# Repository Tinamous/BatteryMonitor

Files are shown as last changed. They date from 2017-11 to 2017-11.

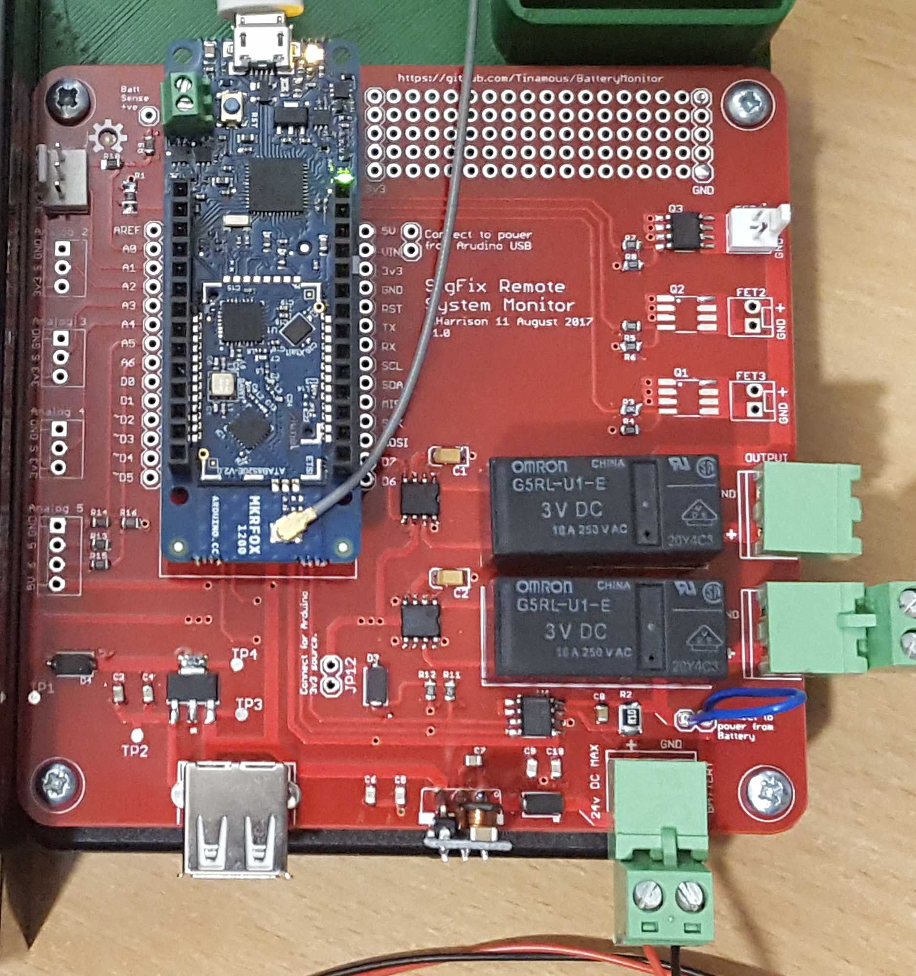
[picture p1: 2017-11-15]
Arduino/Images/Assembled2.jpg

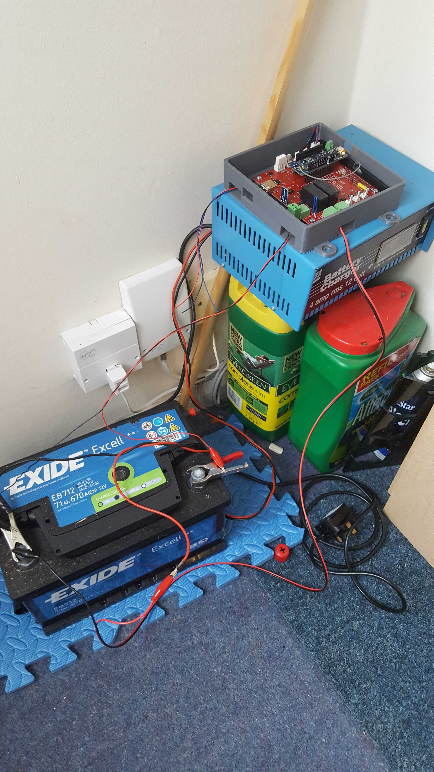
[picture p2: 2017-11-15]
Arduino/Images/TestSetup.jpg

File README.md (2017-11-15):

Internet Of Things Remote System Monitor
========================================

For remote locations a battery powered devices may be the only realistic way of powering equipment, these may be left to work for months or years until one day the battery dies or goes flat unexpectedly or something else happens.

This project uses the Sigfox Arduino MKR FOX 1200 to provide low power wireless internet connectivity and a INA219 to monitor the battery. This allows monitor and early notification of problems.

Additionally 2x latching relays, 3x N-Channel fets and some digital/analog inputs provide means to monitor other parts of a system as well (e.g. monitor switches, water levels, control pumps, lights etc.).

The system is composed of:

* Arduino MKR FOX 1200 Sigfox based Arduino.
* INA219 power monitor (0R1 resistor - limited to 2A due to package size).
* 2x Latching relays for output and charger input.
* 3x N-Channel FET outputs.
* 6x Analog input connectors (4x 3 pin with GND, 3v3 and signal, 1x 4 pin with GND 5V and 2x signal divided to allow 5V analog).
* On-board 5V buck regulator from the battery.
* On-board 3v3 regulator for relay and analog connectors.
* Mini prototyping area.
* Always on USB A power output.

Primary Use Case - Garage
=========================

* 12V Lead Acid Battery (i.e. car battery) connected to the battery input
* Powered system connected to the output (humidity controlled boxes).
* Solar charger connected to charger connector.
* LED lighting connected to FET1, 2 and 3.

Alternative Usages:
* The battery connector can be used as an output with inputs from 2 batteries or a power supply and battery allowing a backup power source to be switched in should the primary fall out of acceptable range. In this case the power measurement is purely for output and does not include power used through the FET outputs, analog inputs or the system itself.

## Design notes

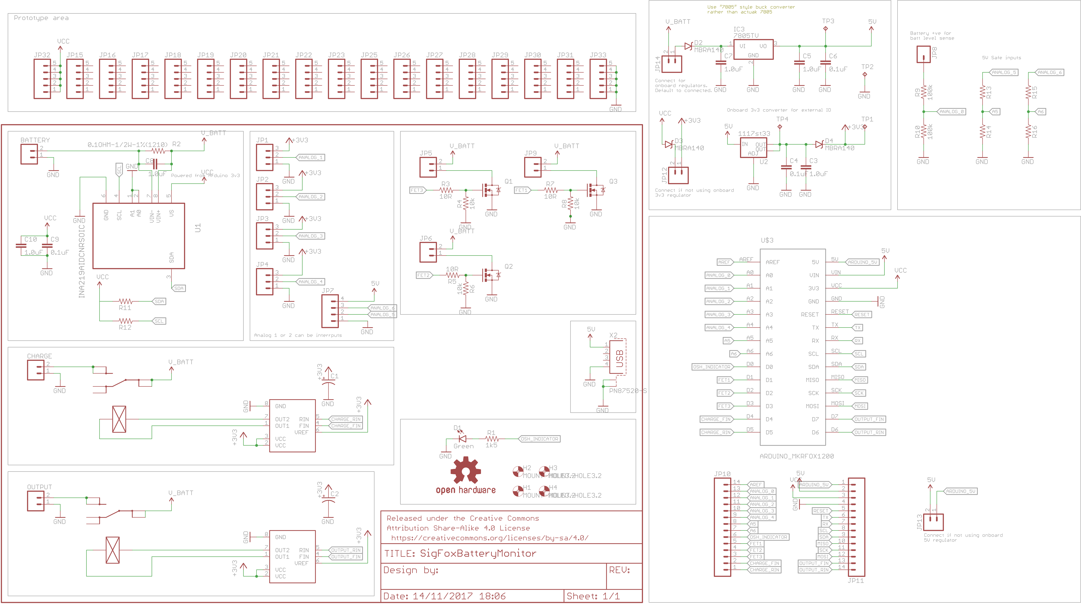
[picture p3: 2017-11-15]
Arduino/Images/Schematic.png

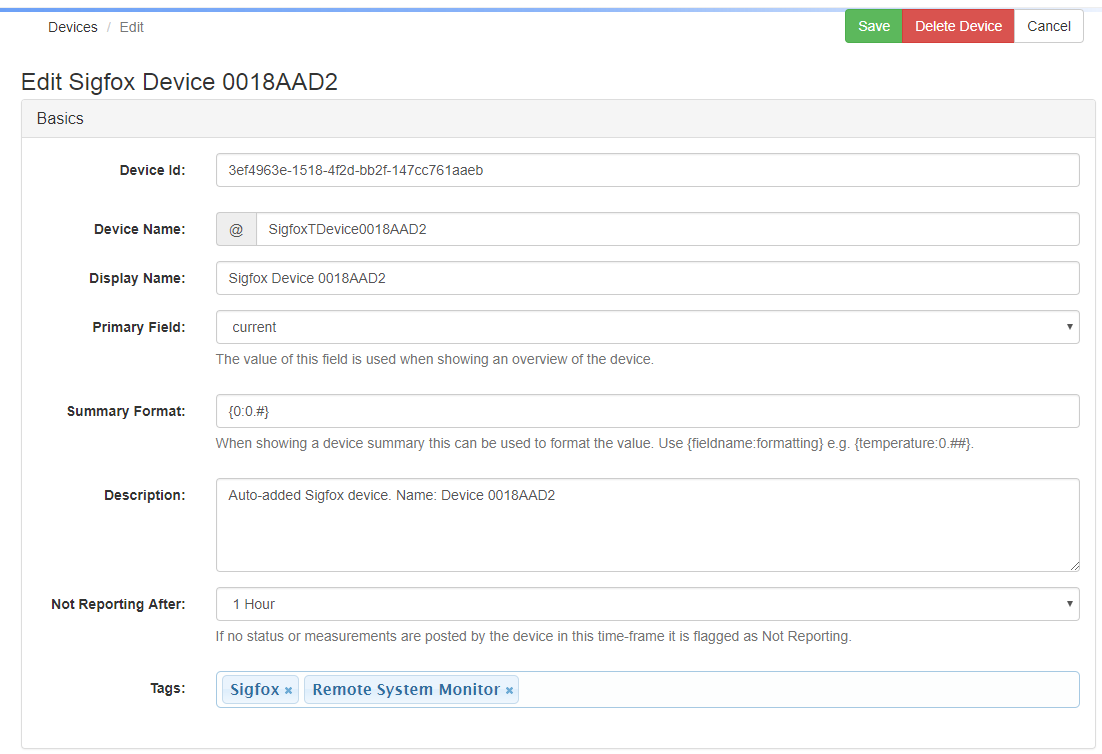
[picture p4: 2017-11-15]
Arduino/Images/EditDevice.png

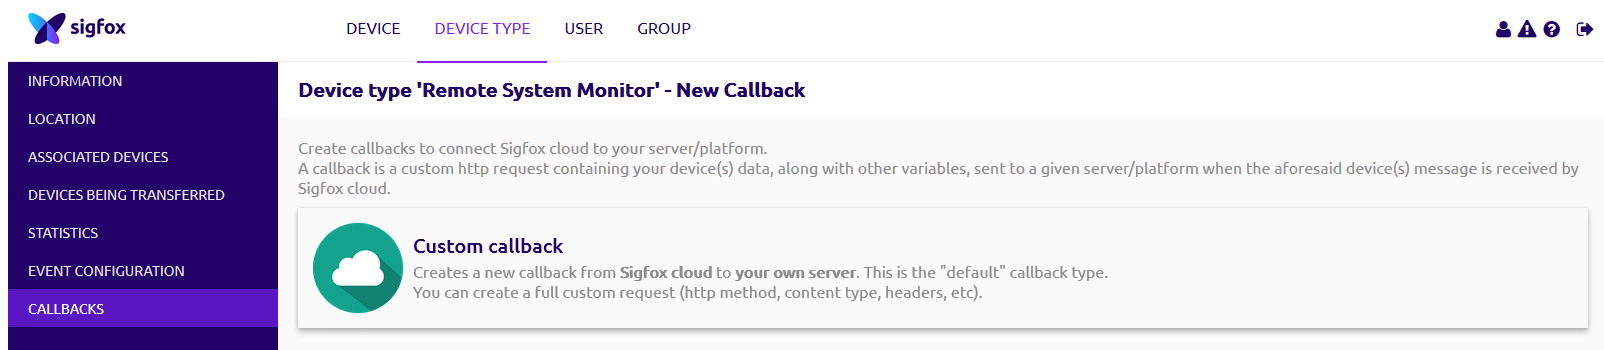
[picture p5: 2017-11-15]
Arduino/Images/CustomCallback.png

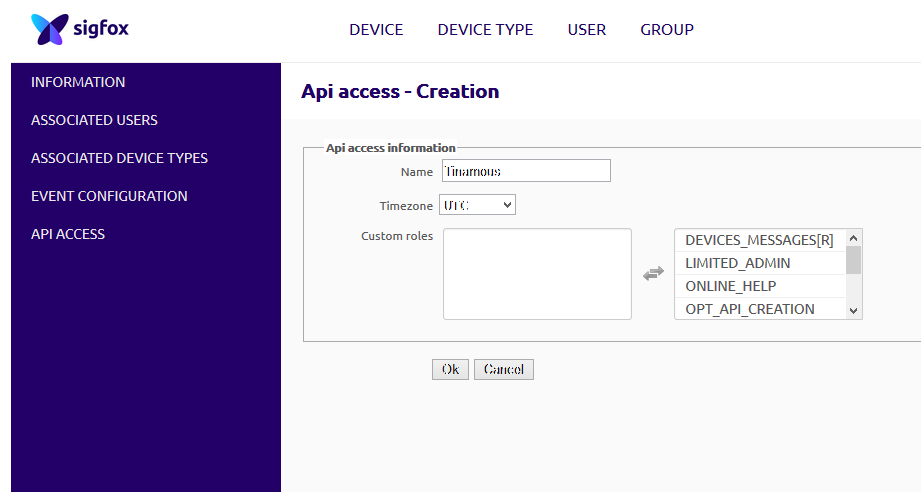
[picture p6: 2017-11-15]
Arduino/Images/ApiSettings.png

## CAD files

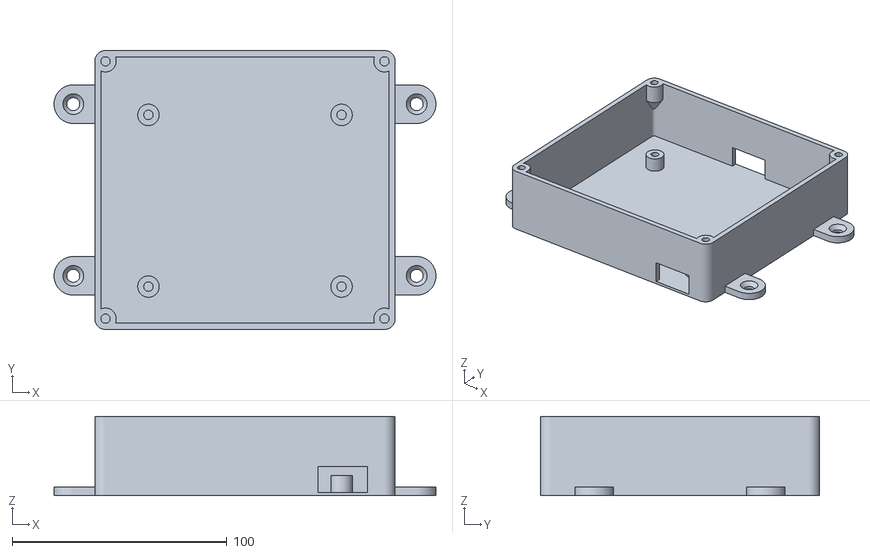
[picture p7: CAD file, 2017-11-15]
Arduino/Case/GarageLightsControllerBox.stl
178.0 x 130.0 x 37.0

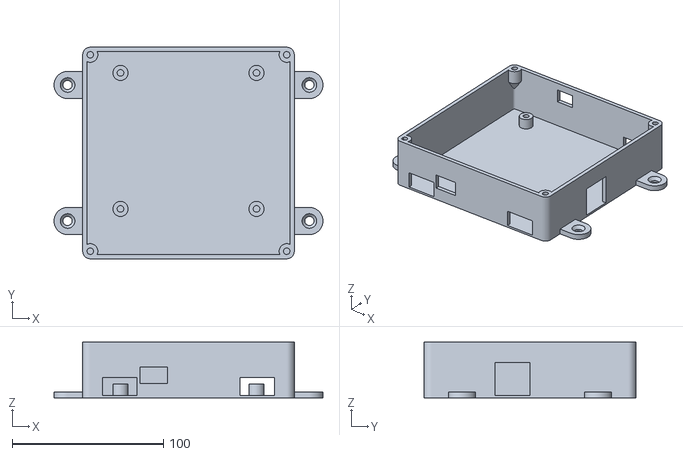
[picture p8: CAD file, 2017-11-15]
Arduino/Case/BatteryMonitorCase.stl
178.0 x 140.0 x 37.0

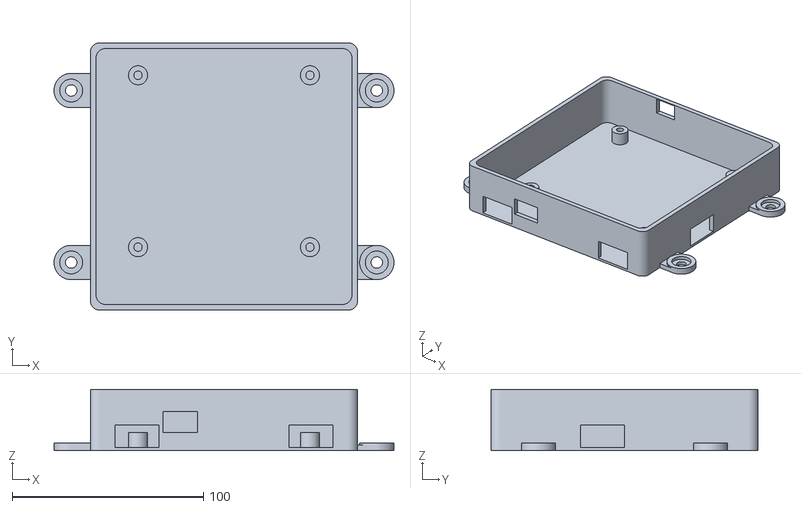
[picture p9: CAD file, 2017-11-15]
Arduino/Case/BatteryMonitorCase-LowerTrunking.stl
178.0 x 140.0 x 32.0

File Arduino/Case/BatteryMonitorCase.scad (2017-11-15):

$fn=80;

// Width (Note pcb does not centre align).
// 120mm realisting minimum size
// with trunking
// Width of 140mm allows the aerial to be stuck to the top edge
width = 140;

// Overall length /mm (without aerial 117mm, With aerial 125mm)
length = 140;

//enclosureHeight = 32; // Max for USB being in top part.
enclosureHeight = 37; // Max for USB being in top part.

// 100x100 for general PCB
pcbWidth = 100; // x direction
pcbLength = 100; // y direction
// Offset from edge for the PCB mounting hole
pcbMountOffset = 5;


pcbXOffset = (width - pcbWidth)/2 ;
//pcbYOffset = (length - pcbLength)/2 + 10;
// Keep the PCB 10mm from the top edge
// allows the aerial to be stuck down.
// make gap 21mm for Arduiono MRK 1000 (WiFi)
pcbYOffset = (length - pcbLength - 12); 

// Kitchen Lights
// Center.
//pcbYOffset = (length - pcbLength - 25);

echo ("pcbXOffset",pcbXOffset);
echo ("pcbYOffset",pcbYOffset);

// 20mm border around the PCB for connectors.

// Thickness of the base material.
baseHeight = 1.5;

// How height off the base the PCB wil lbe.
height = 8;

//wallThickness = 1.5;
wallThickness = 3;

// Diameter of the screw hole for the PCB mounts. 4.4mm works well for M3 heatfits.
pcbMountScrewHoleDiameter = 4.4;

// caseOptions

addPowerSideHoles = true;
addFetHoles = false; 
addSensorSideHoles = false;
addArduinoUsbHole = true;

// Top 
addTopMiddleRoundConduitHole = false;
addTopRightTrunkingInlet = true;
addTopCenterTrunkingInlet = false;

// Bottom
addMiddleRoundConduitHole = false;
addTwinConduitHoles = false;
addPowerLowerTrunkingInlet = true;
addSecondLowerTrunkingInlet = true;
addUsbOutletHole = true;

addMountingTabs = true;

conduitHoleDiameter = 22;

mountingTabYOffset = 25;
countersunkMountingScrews = true;

// Screw or threaded insert
lidScrewDiameter = pcbMountScrewHoleDiameter; //4.4
includeLidScrewMounts = true;
            
// Make it a nice distance appart for the holes.
// that doesn't change if the case is made larger
// allowing it to be swapped out.
twinHolesDistanceApart = 45;  // Gives round hole by USB...
//twinHolesDistanceApart = 90; // On the edges - good for USB access
twinHolesXOffset = (width - twinHolesDistanceApart) / 2;

module roundedCube(width, height, depth, cornerDiameter) {
//cornerDiameter = 5;
cornerRadius = cornerDiameter/2;

    translate([cornerDiameter/2,0,0]) {
        cube([width-cornerDiameter, height, depth]);
    }
    
    translate([0,cornerDiameter/2,0]) {
        cube([width, height-cornerDiameter, depth]);
    }
    
    translate([cornerRadius,cornerRadius,0]) {
        cylinder(d=cornerDiameter, h=depth);
    }
    
    translate([width-cornerRadius,cornerRadius,0]) {
        cylinder(d=cornerDiameter, h=depth);
    }
    
    translate([cornerRadius,height-cornerRadius,0]) {
        cylinder(d=cornerDiameter, h=depth);
    }
    
    translate([width-cornerRadius,height-cornerRadius,0]) {
        cylinder(d=cornerDiameter, h=depth);
    }
}

module screw(x,y, height) {
    translate([x,y, 0]) {
        cylinder(d=6.5, h=2);
    }
    
    translate([x,y, -4]) {
        cylinder(d=3, h=6);
    }
}

module genericPcb() {
    
//pcbWidth = 100;
//pcbLength = 100;
// Offset from edge for the PCB mounting hole
//pcbMountOffset = 5;
    
    roundedCube(pcbWidth,pcbLength , 1.6, 8);
    screw(pcbMountOffset, pcbMountOffset, height, baseHeight);
    screw(pcbMountOffset,pcbLength - pcbMountOffset, height, baseHeight);
    screw(pcbWidth - pcbMountOffset, pcbMountOffset, height, baseHeight);
    screw(pcbWidth - pcbMountOffset,pcbLength - pcbMountOffset, height, baseHeight);
}

// Arduino System Monitor PCB.
module arduinoSystemMonitorPcb() {
    roundedCube(100,100, 1.6, 8);
    screw(5,5, height, baseHeight);
    screw(5,95, height, baseHeight);
    screw(95,5, height, baseHeight);
    screw(95,95, height, baseHeight);
    
    // Battery in
    translate([74, -14, 1.6]) {
        cube([12, 22, 14]);
    }
    
    // Charger out
    translate([90, 19, 1.6]) {
        cube([22, 12, 14]);
    }
    
    // Power out
    translate([90, 35, 1.6]) {
        cube([22, 12, 14]);
    }
    
    // FETs
    translate([90, 75, 1.6]) {
        cube([8, 5, 20]);
    }
    
    translate([90, 59+5, 1.6]) {
        cube([8, 5, 20]);
    }
    
    translate([90, 47+5, 1.6]) {
        cube([8, 5, 20]);
    }
    
    // USB socket
    translate([20.5, -25, 1.6]) {
        cube([13.5, 35, 8]);
    }
    
    // USB Plug into the socket
    translate([19.5, -50, 1.6]) {
        cube([15.5, 50, 8]);
    }
    
    // Analog 1..5
    translate([2, 75+5, 1.6]) {
        cube([8, 7, 20]);
    }
    
    translate([2, 63.5+5, 1.6]) {
        cube([8, 7, 20]);
    }
    
    translate([2, 51.5+5, 1.6]) {
        cube([8, 7, 20]);
    }
    
    translate([2, 39.5+5, 1.6]) {
        cube([8, 7, 20]);
    }
    
    translate([2, 24+5, 1.6]) {
        cube([8, 12, 20]);
    }
}

// Actually this needs to be a Sigfor module...
module arduino() {
    // Z position already at PCB top.
    cube([25,68,14.5]);
    // Headers and Battery terminal
    translate([0,10,0]) {
        cube([5,50,23]); // Includes battery connector
        translate([20,0,0]) {
            cube([5,36,23]);
        }
    }
      
    // USB
    translate([8, 68-5.5, 14.5]) {
        cube([8,5.5,3]);
    }
    
    // USB Plug
    translate([8 - (3/2), 68, 14.5 - 3]) {
        cube([11,22,8]);
    }
    
    // Aerial connector
    translate([16, 5, 24]) {
        cube([8,4,2.5]);
    }
}

module pcbMount(x,y, height, baseHeight) {
    translate([x,y, baseHeight-0.1]) {
        difference() {
            cylinder(d=10, h=height);
            cylinder(d=pcbMountScrewHoleDiameter, h=height);
        }
    }
}

module pcbMountPin(x,y, height, baseHeight) {
    translate([x,y, baseHeight-0.1]) {
        union() {
            cylinder(d=10, h=height);
            cylinder(d=pcbMountPinDiameter, h=height + 3);
        }
    }
}

module addPcbMounts() {
    
    //pcbWidth = 100;
    //pcbLength = 100;
    // Use pins on the end two to make it easier to 
    pcbMount(pcbMountOffset,pcbMountOffset, height, baseHeight);
    #pcbMount(pcbWidth - pcbMountOffset,pcbMountOffset, height, baseHeight);
    
    pcbMount(pcbMountOffset,pcbLength - pcbMountOffset, height, baseHeight);
    pcbMount(pcbWidth - pcbMountOffset,pcbLength - pcbMountOffset, height, baseHeight);
}

module base() {       

// Offset from Pcb X for the Power In port.    
//powerInPcbOffset = 69; // Align with PCB
powerInPcbOffset = 84; // Gives trunking holes on edge (works better for USB.)
trunkingPortWidth = 23;
// Make a second trunking inlet on the lower
// part and make it's offset from the left
// symetrical with the power inlet.
secondTrunkingXOffset = width - (pcbXOffset + powerInPcbOffset + trunkingPortWidth);
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

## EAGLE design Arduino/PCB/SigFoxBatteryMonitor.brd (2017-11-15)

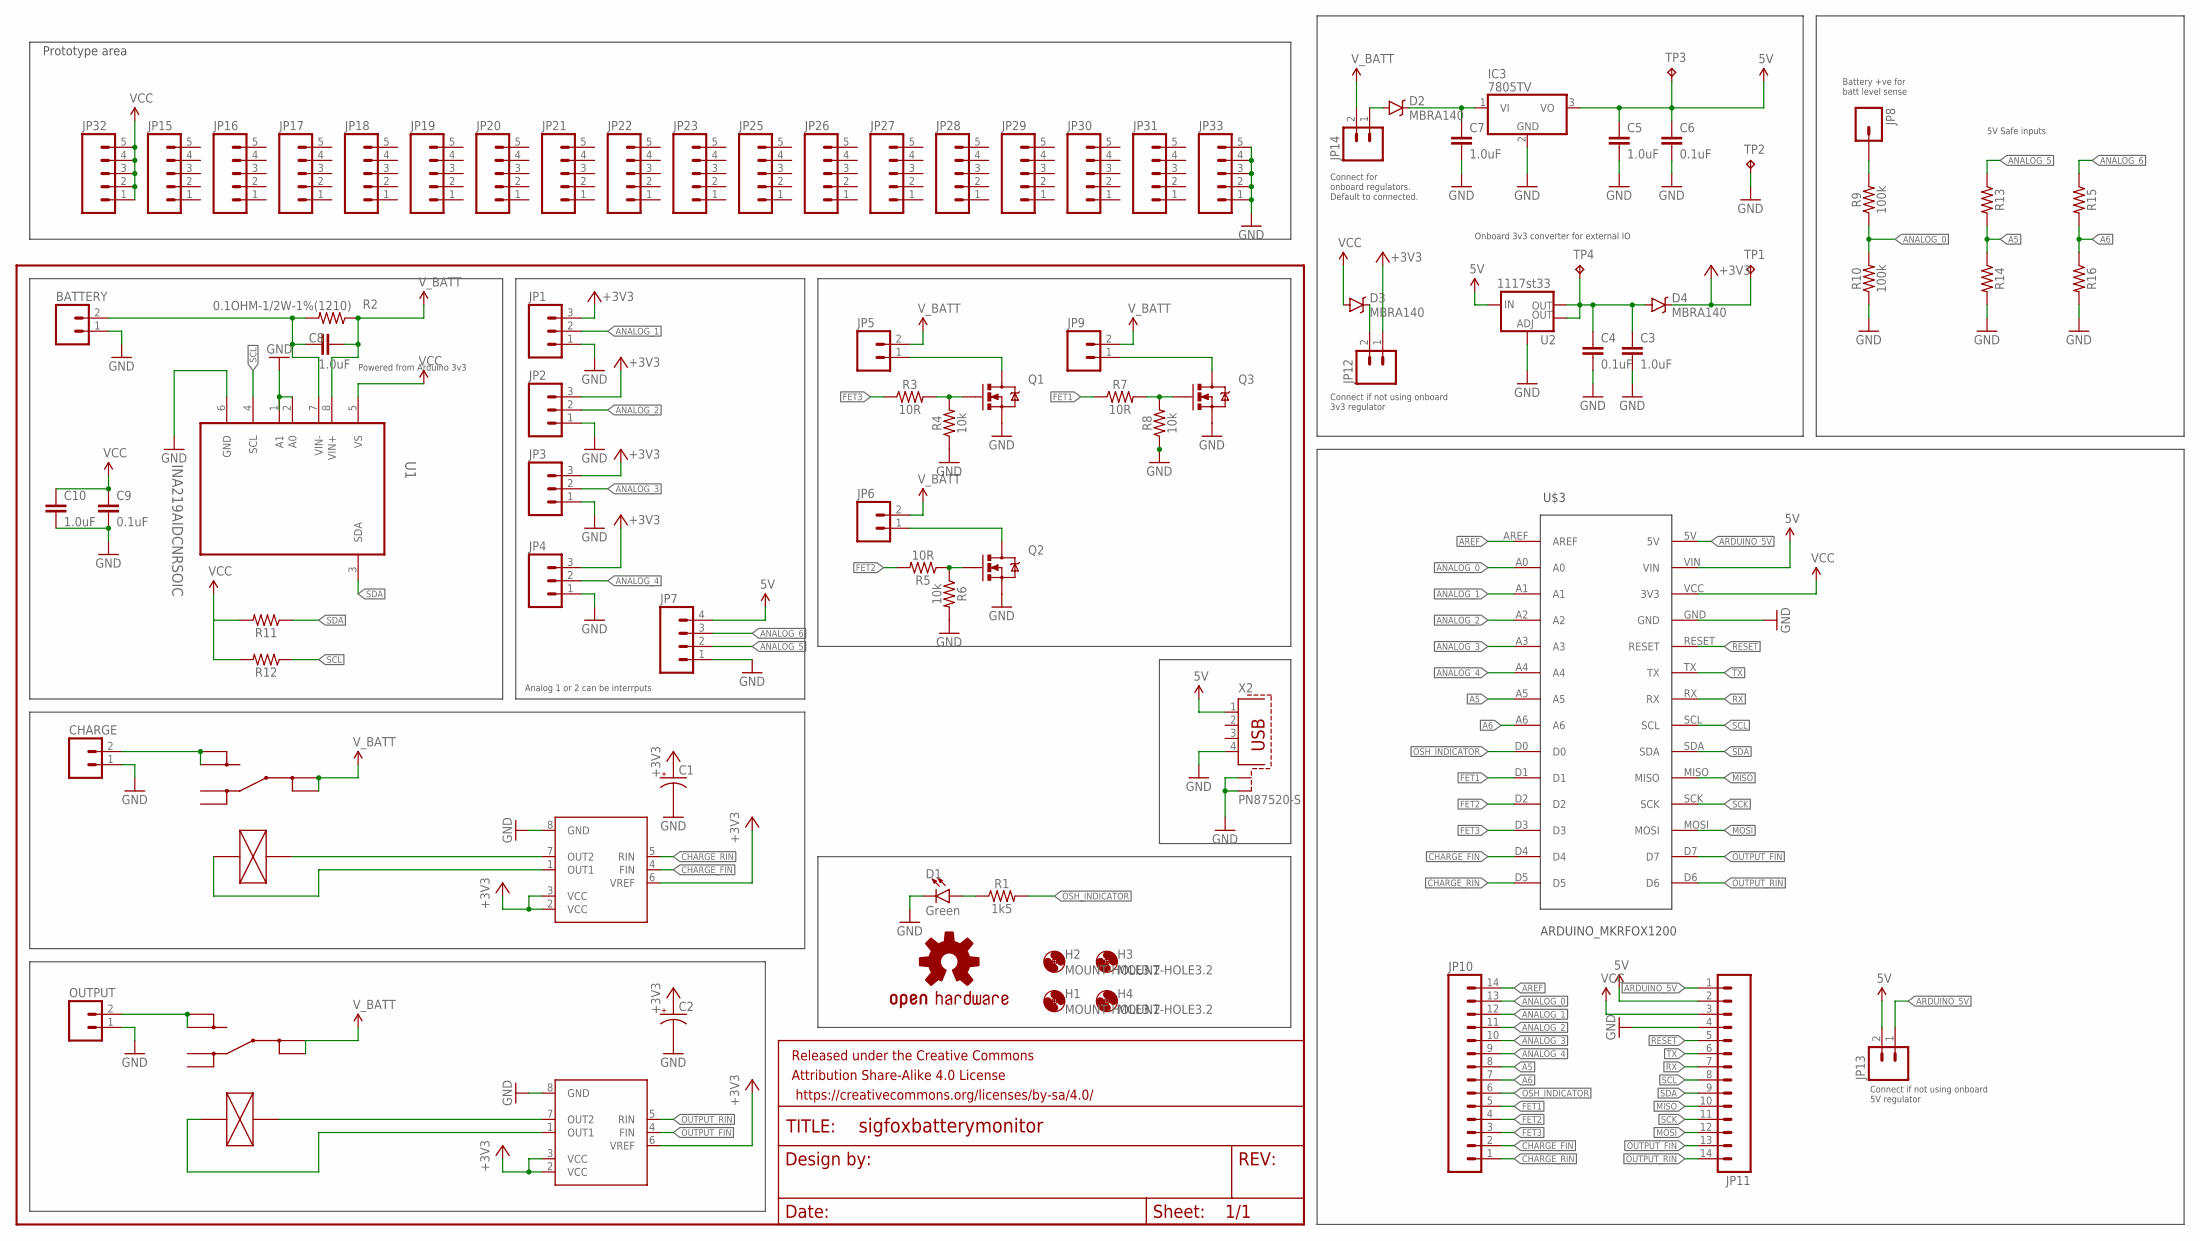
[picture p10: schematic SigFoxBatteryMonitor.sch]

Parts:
BATTERY: M025MM; SCREWTERMINAL-5MM-2; FARNELL 2493689
C1, C2: CAP_POL1206; EIA3216; FARNELL 1457413
C3, C5, C7, C8, C10: 1.0uF; 0805
C4, C6, C9: 0.1uF; 0805
CHARGE: M025MM; SCREWTERMINAL-5MM-2; FARNELL 2493689
D1: Green; LED-1206-BOTTOM
D2, D3, D4: MBRA140; SMA-DIODE
FRAME1: FRAME-LETTER; CREATIVE_COMMONS
H1, H2, H3, H4: MOUNT-HOLE3.2; 3,2
IC1, IC2: BD6211F; SOP8; FARNELL 1716256
IC3: 7805TV; TO220V
JP1, JP2, JP3, JP4: M03POLAR; MOLEX-1X3
JP5, JP6, JP9: M02POLAR; MOLEX-1X2
JP7: M04POLAR; MOLEX-1X4
JP8: M01PTH; 1X01
JP10, JP11: M14; 1X14
JP12, JP13, JP14: M02PTH; 1X02
JP15, JP16, JP17, JP18, JP19, JP20, JP21, JP22, JP23, JP25, JP26, JP27, JP28, JP29, JP30, JP31: M05NO_SILK; 1X05_NO_SILK
JP32, JP33: M05PTH; 1X05
LOGO1: OSHW-LOGOM; OSHW-LOGO-M
OUTPUT: M025MM; SCREWTERMINAL-5MM-2; FARNELL 2493689
Q1, Q2, Q3: IRF7413Z; SO08; FARNELL 2468020
R1: 1k5; 1206
R2: 0.1OHM-1/2W-1%(1210); 1210
R3, R5, R7: 10R; 0805
R4, R6, R8: 10k; 0805
R9, R10: 100k; 0805
R11, R12, R13, R14, R15, R16: 0805
TP1: 3v3; TP15R
TP2: GND; TP15R
TP3, TP4: 5v; TP15R
U1: INA219AIDCNRSOIC; SO08
U2: 1117st33; SOT223; FARNELL 1652366
U$1, U$2: RELAY_G5RL-1E; G5RL-1E; FARNELL 2432863
U$3: ARDUINO_MKRFOX1200
X2: PN87520-S

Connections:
5V: C5.1, C6.1, IC3.3 (VO), JP7.4, JP11.2, JP13.2, TP3.TP, U2.3 (IN), U$3.VIN, X2.1
+3V3: C1.A (+), C2.A (+), D4.C, IC1.2 (VCC), IC1.3 (VCC), IC1.6 (VREF), IC2.2 (VCC), IC2.3 (VCC), IC2.6 (VREF), JP1.3, JP2.3, JP3.3, JP4.3, JP12.1, TP1.TP
A5: JP10.8, R13.2, R14.1, U$3.A5
A6: JP10.7, R15.2, R16.1, U$3.A6
ANALOG_0: JP10.13, R9.1, R10.2, U$3.A0
ANALOG_1: JP1.2, JP10.12, U$3.A1
ANALOG_2: JP2.2, JP10.11, U$3.A2
ANALOG_3: JP3.2, JP10.10, U$3.A3
ANALOG_4: JP4.2, JP10.9, U$3.A4
ANALOG_5: JP7.2, R13.1
ANALOG_6: JP7.3, R15.1
ARDUINO_5V: JP11.1, JP13.1, U$3.5V
AREF: JP10.14, U$3.AREF
CHARGE_FIN: IC1.4 (FIN), JP10.2, U$3.D4
CHARGE_RIN: IC1.5 (RIN), JP10.1, U$3.D5
FET1: JP10.5, R7.1, U$3.D1
FET2: JP10.4, R5.2, U$3.D2
FET3: JP10.3, R3.1, U$3.D3
GND: BATTERY.1, C1.C (-), C2.C (-), C3.2, C4.2, C5.2, C6.2, C7.2, C9.2, C10.2, CHARGE.1, D1.C, IC1.8 (GND), IC2.8 (GND), IC3.2 (GND), JP1.1, JP2.1, JP3.1, JP4.1, JP7.1, JP11.4, JP33.1, JP33.2, JP33.3, JP33.4, JP33.5, OUTPUT.1, Q1.1 (S), Q1.2 (S), Q1.3 (S), Q2.1 (S), Q2.2 (S), Q2.3 (S), Q3.1 (S), Q3.2 (S), Q3.3 (S), R4.1, R6.2, R8.1, R10.1, R14.2, R16.2, TP2.TP, U1.1 (A1), U1.2 (A0), U1.6 (GND), U2.1 (ADJ), U$3.GND, X2.4, X2.S1, X2.S2
MISO: JP11.10, U$3.MISO
MOSI: JP11.12, U$3.MOSI
unnamed: D1.A, R1.1
unnamed: OUTPUT.2, U$1.NO@1 (NO), U$1.NO@2 (NO)
unnamed: CHARGE.2, U$2.NO@1 (NO), U$2.NO@2 (NO)
unnamed: Q1.4 (G), R3.2, R4.2
unnamed: JP5.1, Q1.5 (D), Q1.6 (D), Q1.7 (D), Q1.8 (D)
unnamed: Q3.4 (G), R7.2, R8.2
unnamed: BATTERY.2, C8.1, R2.2, U1.7 (VIN-)
unnamed: IC2.7 (OUT2), U$1.COIL-
unnamed: IC2.1 (OUT1), U$1.COIL+
unnamed: IC1.7 (OUT2), U$2.COIL-
unnamed: IC1.1 (OUT1), U$2.COIL+
unnamed: Q2.4 (G), R5.1, R6.1
unnamed: JP9.1, Q3.5 (D), Q3.6 (D), Q3.7 (D), Q3.8 (D)
unnamed: D3.C, JP12.2
unnamed: JP6.1, Q2.5 (D), Q2.6 (D), Q2.7 (D), Q2.8 (D)
unnamed: JP8.1, R9.2
unnamed: C7.1, D2.C, IC3.1 (VI)
unnamed: D2.A, JP14.1
unnamed: C3.1, C4.1, D4.A, TP4.TP, U2.2 (OUT), U2.4 (OUT)
OSH_INDICATOR: JP10.6, R1.2, U$3.D0
OUTPUT_FIN: IC2.4 (FIN), JP11.13, U$3.D7
OUTPUT_RIN: IC2.5 (RIN), JP11.14, U$3.D6
RESET: JP11.5, U$3.RESET
RX: JP11.7, U$3.RX
SCK: JP11.11, U$3.SCK
SCL: JP11.8, R12.1, U1.4 (SCL), U$3.SCL
SDA: JP11.9, R11.1, U1.3 (SDA), U$3.SDA
TX: JP11.6, U$3.TX
VCC: C9.1, C10.1, D3.A, JP11.3, JP32.1, JP32.2, JP32.3, JP32.4, JP32.5, R11.2, R12.2, U1.5 (VS), U$3.VCC (3V3)
V_BATT: C8.2, JP5.2, JP6.2, JP9.2, JP14.2, R2.1, U1.8 (VIN+), U$1.COM@1 (COM), U$1.COM@2 (COM), U$2.COM@1 (COM), U$2.COM@2 (COM)

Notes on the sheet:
Onboard 3v3 converter for external IO
Powered from Arduino 3v3
Battery +ve for batt level sense
Connect if not using onboard 5V regulator
Connect if not using onboard 3v3 regulator
Connect for onboard regulators. Default to connected.
5V Safe inputs
Analog 1 or 2 can be interrputs
Prototype area

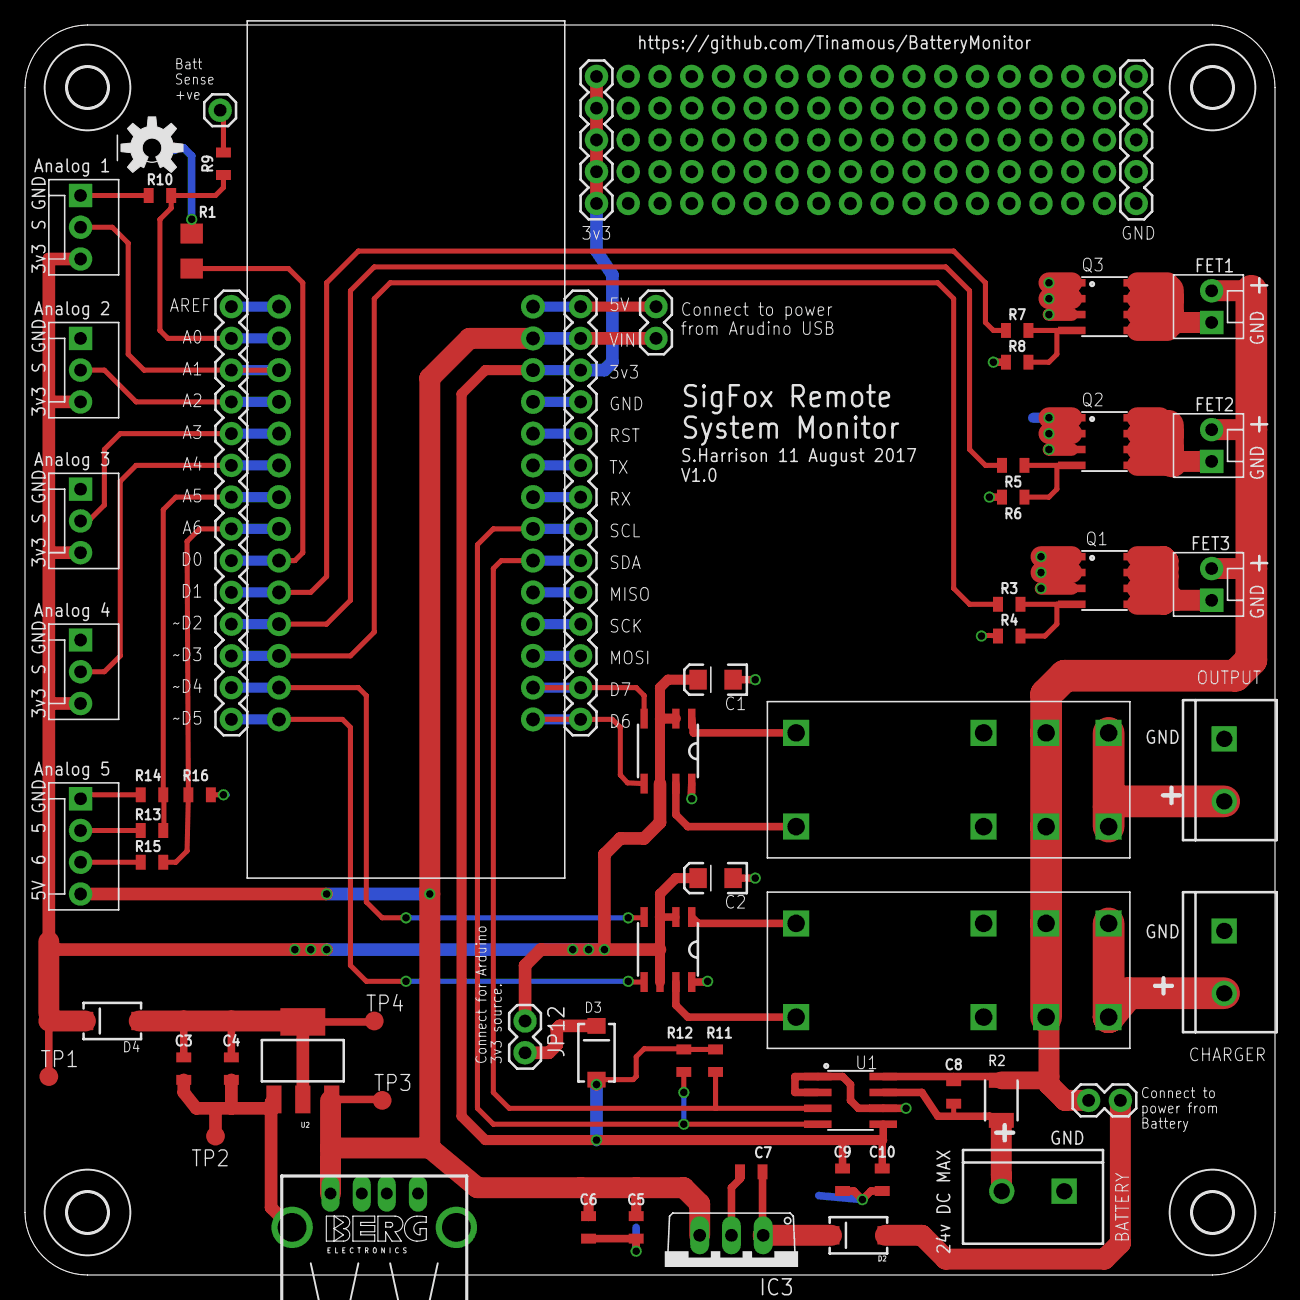
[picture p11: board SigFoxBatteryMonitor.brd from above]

Board: 2 copper layers, 100.0 x 100.0 mm, 87 parts (1 on the bottom side), 51 nets.

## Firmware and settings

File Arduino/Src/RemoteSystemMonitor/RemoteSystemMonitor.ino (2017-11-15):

// Arduino Low Power - Version: Latest 
#include <ArduinoLowPower.h>

// Arduino SigFox for MKRFox1200 - Version: Latest 
#include <SigFox.h>

#include <Wire.h>
#include <Adafruit_INA219.h>

Adafruit_INA219 ina219;

bool fet1State = false;
bool fet2State = false;
bool fet3State = false;
bool outputRelay = false;
bool chargeRelay = false;
bool oshLed = false;

int loopCounter  =0;
bool debug = true;

// First run request downlink data
// from the Sigfox backend.
bool requestDownlinkData = true;

// status::uint:8 version::uint:8 temperature::int:8 current::int:16 voltage::uint:16 humidity::int:16 light::uint:8 light2::uint:8 lastStatus::uint:8
typedef struct __attribute__ ((packed)) sigfox_message {
  uint8_t status;     // status::uint:8 -> Split to 8 bits
  uint8_t version;    // version::uint:8
  int16_t temperature; // temperature::int:16:little-endian
  int16_t current;    // current::int:16:little-endian (e.g. 1159 mA -> 0487 but stored as 8704)
  uint16_t voltage;   // voltage::uint:16:little-endian
  int16_t currentOffCharge;   // currentOffCharge::int:16:little-endian
  uint16_t voltageOffCharge;   // voltageOffCharge::uint:16:little-endian
} SigfoxMessage;

// stub for message which will be sent
SigfoxMessage msg;

void setup() {
  pinMode(0, OUTPUT); // led
  pinMode(1, OUTPUT); // Fet1
  pinMode(2, OUTPUT); // Fet2
  pinMode(3, OUTPUT); // Fet3
  pinMode(4, OUTPUT); // charge relay FIN
  pinMode(5, OUTPUT); // charge relay RIN
  pinMode(6, OUTPUT); // output relay FIN
  pinMode(7, OUTPUT); // output relay RIN
  
  setFetOutput(1, fet1State);
  setFetOutput(2, fet2State);
  setFetOutput(3, fet3State);
  // On to indicate in setup
  setOshLed(true);
  
  // Intialize the relays to off
  // whilst in set-up. Force state so we know
  // the state their in and can then track it.
  setChargeRelay(false, true);
  setOutputRelay(false, true);
  
  //Initialize serial and wait for port to open:
  if (debug) {
    Serial.begin(9600);
  }
     
  // Initialize the INA219.
  // By default to (32V, 2A).  
  ina219.begin();
 
  setupSigfox();  

  if (debug) {
    Serial.println("System Monitor Setup Complete... V0.0.4");
  }
  
  // turn off the OSH Led now set-up is complete.
  setOshLed(false);
}

void setupSigfox() {
  if (!SigFox.begin()) {
    Serial.println("Shield error or not present!");
    return;
  }
  
  // Enable debug led and disable automatic deep sleep
  // Comment this line when shipping your project :)
  if (debug) {
    SigFox.debug();
  }

  // Output the ID and PAC needed to register the 
  // device at the Sigfox backend.
  String version = SigFox.SigVersion();
  String ID = SigFox.ID();
  String PAC = SigFox.PAC();

  // Display module informations
  Serial.println("MKRFox1200 Sigfox first configuration");
  Serial.println("SigFox FW version " + version);
  Serial.println("ID  = " + ID);
  Serial.println("PAC = " + PAC);

  Serial.println("");

  Serial.print("Module temperature: ");
  Serial.println(SigFox.internalTemperature());

  Serial.println("Register your board on https://backend.sigfox.com/activate with provided ID and PAC");

  delay(100);

  // Send the module to the deepest sleep
  SigFox.end();
}

void loop(void) 
{ 
  float shuntvoltage = 0;
  float busvoltage = 0;
  float current_mA = 0;
  float loadvoltage = 0;
  
  // V and I when not charging
  // to give an idea of the state of the battery
  float current_off_charge_mA = 0;
  float busvoltage_off_charge = 0;
 
  // Ensure output relay and charge relay are on by default
  // now that we're monitoring.
  setOutputRelay(true, false);
  setChargeRelay(true, false);
     
  // Flip the LED to show we're doing stuff.
  setOshLed(true);

  // Meaure normal running voltage/current.
  shuntvoltage = ina219.getShuntVoltage_mV();
  busvoltage = ina219.getBusVoltage_V();
  current_mA = ina219.getCurrent_mA();
  loadvoltage = busvoltage + (shuntvoltage / 1000);
    
  if (debug) {    
    Serial.println("-------------------------------------------------------");
    Serial.println("Charger connected: ");    
    Serial.print("Bus Voltage:   "); 
    Serial.print(busvoltage); 
    Serial.println(" V");
    
    Serial.print("Current:       "); 
    Serial.print(current_mA); 
    Serial.println(" mA");
    Serial.println("");
    
    Serial.print("Loop counter:  "); 
    Serial.print(loopCounter); 
    Serial.println("");
    
    Serial.println("");
  }
          
  // Flip the LED to show we're doing stuff.
  setOshLed(false);
       
  // 6 (loops) * 10s (delay) gives approx 1 minute 
  // so send an update to Sigfox rather than (when debugging)
  // having to wait the full 15 minutes for a transmission.
  if (loopCounter == 12) {

    // TODO: Don't disable charge relay when voltage is low
    // as we might not be able to re-enable it.
    //
    // Once every Sigfox transmit cycle, disconnect the charger
    // to measure the raw battery voltage and actual load current
    // (otherwise load current excludes current from the charger).
    setChargeRelay(false, false);
    // Little delay to let the battery chemistry settle a little.
    delay(2000);
    current_off_charge_mA = ina219.getCurrent_mA();
    busvoltage_off_charge = ina219.getBusVoltage_V();
    setChargeRelay(true, false);  

    if (debug) {
      Serial.println("Charger disconnected: ");
      Serial.print("Charge Off Voltage:  "); 
      Serial.print(busvoltage_off_charge); 
      Serial.println(" V");
      
      Serial.print("Charge Off Current: "); 
      Serial.print(current_off_charge_mA); 
      Serial.println(" mA");
      
      Serial.println("");
    }
  
    // remove once we have the device details
    //setupSigfox();
    sendToSigfox(busvoltage, current_mA, busvoltage_off_charge, current_off_charge_mA);
  }

  // Reset the loop counter after (hopefully) 15 minutes.
  if (loopCounter > 6 * 15) {
    loopCounter = 0;
  }

  // Monitor every 10s. (2s delay in relay clickyness).
  delay(8000);
  //LowPower.sleep(8 * 1000);
  loopCounter++;
}

void setOshLed(bool state) {
  //Serial.println("Setting OSH LED");
  digitalWrite(0, state);
  oshLed = state;
}

void setOutputRelay(bool state, bool force) {
  
  // Unless forced, ignore instruction if relay already in correct state
  // to save power.
  if (!force) {
    if (outputRelay == state) {
      return;
    }
  }

  if (debug) {    
    Serial.print("Setting output relay: ");
    Serial.println(state);
  }
  
  digitalWrite(6, state);
  digitalWrite(7, !state);
  outputRelay = state;
  
  delay(100);
  digitalWrite(6, LOW);
  digitalWrite(7, LOW);
}

void setChargeRelay(bool state, bool force) {
  // Unless forced, ignore instruction if relay already in correct state
  // to save power.
  if (!force) {
    if (chargeRelay == state) {
      return;
    }
  }

  if (debug) {    
    Serial.print("Setting charge relay: ");
    Serial.println(state);
  }
  
  // FIN/RIN order swapped on charge compared to output.
  digitalWrite(5, state);
  digitalWrite(4, !state);
  chargeRelay = state;
  
  delay(100);
  digitalWrite(4, LOW);
  digitalWrite(5, LOW);
}

void setFetOutput(int fet, bool state) {
  if (debug) {    
    Serial.print("Setting FET: ");
    Serial.print(fet);
    Serial.print(" State: ");
    Serial.println(state);
  }
  
  switch (fet) {
    case 1:
      fet1State = state;
    case 2:
      fet2State = state;
    case 3:
      fet3State = state;
    default:
      // Invalid fet!
      return;
  }
  
  digitalWrite(fet, state);
}

// B7: Battery Flat
// B6: Charge Relay state
// B5: Charging
// B4: Reserved
// B3: Output relay state
// B2: Fet 1 state
// B1: Fet 2 state
// B0: Fet 3 state
byte getStatusFlags(float voltage, float current_mA, float current_charger_off_mA) {
  byte status = 0;
  
  // Upper Nibble (Charging/Battery)
  // Battery flat
  if (voltage < 10.5) {
    status |= 0x80; // 1000 0000
  }

  // Charger relay status
  if (chargeRelay) {
    status |= 0x40; // 0100 0000
  }

  // +ve current flow to the battery means it's charging.
  if (current_mA > 0) {
    status |= 0x20; // 0010 0000
  }

  // Not sure what this means...
  if (current_charger_off_mA > 0) {
    status |= 0x10; // 0001 0000
  }

  // Lower Nibble (Outputs)
  // Output relay enabled.
  if (outputRelay) {
    status |= 0x08; // 0000 1000
  }

  if (fet1State) {
    status |= 0x04; // 0000 0100
  }

  if (fet2State) {
    status |= 0x02; // 0000 0010
  }

  if (fet3State) {
    status |= 0x01; // 0000 0001
  }

  return status;
}

void sendToSigfox(float busvoltage, float current_mA, float busvoltage_off_charge, float current_charger_off_mA) {
  if (debug) {    
    if (requestDownlinkData) { 
      Serial.println("**** Sending to Sigfox with downlink *****");
    } else {
      Serial.println("**** Sending to Sigfox *****");
    }
  }
  SigFox.begin();

  // Wait at least 30mS after first configuration (100mS before)
  delay(100);
  // Clears all pending interrupts
  SigFox.status();
  delay(1);

  // Bytes 0 and 1
  msg.status = getStatusFlags(busvoltage_off_charge, current_mA, current_charger_off_mA);
  msg.version = 3;
  
  msg.temperature = (int16_t)(SigFox.internalTemperature() * 10);
  
  // Charger connected
  // 2000mA is max for PCB (32768 max for signed int. i.e. +/-32 Amps)
  msg.current = (int16_t)(current_mA); 
  // 12.13 -> 1213 (65535 max i.e. 655 Volts)  
  msg.voltage = (uint16_t)(busvoltage * 100); 
  
  // Charger Off (Isolated).
  msg.currentOffCharge = (int16_t)(current_charger_off_mA); 
  msg.voltageOffCharge = (uint16_t)(busvoltage_off_charge * 100);

  Serial.println("Sending packet...");
  SigFox.beginPacket();
  SigFox.write((uint8_t*)&msg, 12);
  // endPacket actually sends the data.
  uint8_t lastMessageStatus = SigFox.endPacket(requestDownlinkData);
  
  if (requestDownlinkData) {
    parseDownlinkData(lastMessageStatus);
  }
  
  SigFox.end();
  
  // Ensure downliad link is cleared after sending to Sigfox.
  // TODO: Re-enable this every 6 hours (Max 4x per 24 hours).
  requestDownlinkData = false;
  
  if (debug) {    
    Serial.println("Status: " + String(lastMessageStatus));
  
    if (lastMessageStatus > 0) {
      Serial.println("No transmission!");
    }  
  }
}

void parseDownlinkData(uint8_t lastMessageStatus) {
  if (lastMessageStatus > 0) {
    Serial.println("No transmission. Status: " + String(lastMessageStatus));
    return;
  }

  // Max response size is 8 bytes
  // set-up a empty buffer to store this. (0x00 == no action for us.)
  // each byte has meaning for control.
  uint8_t response[] = {0x00, 0x00, 0x00, 0x00, 0x00, 0x00, 0x00, 0x00 };

  // Response packet needs parsePacket to be called
  // before being read.
  if (SigFox.parsePacket()) {
    
    Serial.println("Response from server:");
    int i = 0;
    while (SigFox.available()) {
      Serial.print("0x");
      int readValue = SigFox.read();
      Serial.println(readValue, HEX);
      response[i] = (uint8_t)readValue;
      i++;
    }

    // byte 0 - relay control.
    parseRelayControl(response[0]);
    // byte 1 - FETs control
    parseFETControl(response[1]);
    // byte 2 - GPIO output?
    
  } else {
    Serial.println("No response from server");
  }
  Serial.println();
}

void parseRelayControl(uint8_t value) {
  // TODO: implement.
  // 00 : Ignore
  // 01 : Off
  // 10 : on
  // 11 : invalid
  // Bits 7 & 6 = > Output relay
  // Bits 5 & 4 = > Charge relay
  // Bits 3 & 2 = > Ignored
  // Bits 1 & 0 = > Ignored
  Serial.println("Setting relays from:");
  Serial.println(value, HEX);
  Serial.println("");
}

void parseFETControl(uint8_t value) {
  // TODO: Implement.
  // 00 : Ignore
  // 01 : Off
  // 10 : on
  // 11 : invalid
  // Bits 7 & 6 = > Fet 1
  // Bits 5 & 4 = > Fet 2
  // Bits 3 & 2 = > Fet 3
  // Bits 1 & 0 = > Ignored
  Serial.println("Setting FET outputs from:");
  Serial.println(value, HEX);
  Serial.println("");
}

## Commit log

2017-08-11 Start of Arduino MKRFOX1200 based battery monitor
    [SigFoxBatteryMonitor.brd, SigFoxBatteryMonitor.sch]
2017-09-03 Version 1.0 PCB.
    [SigFoxBatteryMonitor.brd, SigFoxBatteryMonitor.sch]
2017-09-17 Added customisable case
    [BatteryMonitorCase.scad]
2017-11-15 Fixed type on silkscreen and improved layout of schematic.
    [SigFoxBatteryMonitor.brd, SigFoxBatteryMonitor.sch]
2017-11-15 Adding arduino code.
2017-11-15 Improvements to the enslosure
    [BatteryMonitorCase-LowerTrunking.stl, BatteryMonitorCase.scad, BatteryMonitorCase.stl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]

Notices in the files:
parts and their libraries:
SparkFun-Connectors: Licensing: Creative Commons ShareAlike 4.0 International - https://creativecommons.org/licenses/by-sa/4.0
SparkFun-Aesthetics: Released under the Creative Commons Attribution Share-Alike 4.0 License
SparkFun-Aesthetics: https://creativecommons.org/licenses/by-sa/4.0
